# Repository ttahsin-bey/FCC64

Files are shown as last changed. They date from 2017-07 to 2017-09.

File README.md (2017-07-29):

# FCC64
Final Chess Card - Forum64 Edition

Current Design:

Rendering

Recent Prototype:

Prototype

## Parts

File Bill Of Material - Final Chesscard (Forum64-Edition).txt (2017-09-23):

Ref	Product		Package	Value			Distri	Order-Code

R1	Resistor	0603	100k, 1%		Mouser	603-RC0603FR-07100KL
R2	Resistor	0603	100k, 1%		Mouser	603-RC0603FR-07100KL
R3	Resistor	0603	100k, 1%		Mouser	603-RC0603FR-07100KL
R4	Resistor	0603	100k, 1%		Mouser	603-RC0603FR-07100KL
R5	Resistor	0603	33R, 1%			Mouser	603-RC0603FR-0733RL
R6	Resistor	0603	3k4, 1%			Mouser	603-RC0603FR-073K4L
R7	Resistor	0603	1k15, 1%		Mouser	603-RC0603FR-071K15L
R8	Resistor	0603	2k2, 1%			Mouser	603-RC0603FR-072K2L
R9	Resistor	0603	2k2, 1%			Mouser	603-RC0603FR-072K2L
R10	Resistor	0603	2k2, 1%			Mouser	603-RC0603FR-072K2L
R11	Resistor	0603	2k2, 1%			Mouser	603-RC0603FR-072K2L
R12	Resistor	0603	2k2, 1%			Mouser	603-RC0603FR-072K2L

C1	Capacitor	1206	10µF/25V, X7R, MLCC	Mouser	603-CC126KKX7R8BB106
C2	Capacitor	1206	10µF/25V, X7R, MLCC	Mouser	603-CC126KKX7R8BB106
C3	Capacitor	0603	100nF/50V, X7R, MLCC	Mouser	603-CC603KRX7R9BB104
C4	Capacitor	0603	100nF/50V, X7R, MLCC	Mouser	603-CC603KRX7R9BB104
C5	Capacitor	0603	100nF/50V, X7R, MLCC	Mouser	603-CC603KRX7R9BB104
C6	Capacitor	0603	100nF/50V, X7R, MLCC	Mouser	603-CC603KRX7R9BB104
C7	Capacitor	0603	100nF/50V, X7R, MLCC	Mouser	603-CC603KRX7R9BB104
C8	Capacitor	0603	100nF/50V, X7R, MLCC	Mouser	603-CC603KRX7R9BB104
C9	Capacitor	0603	100nF/50V, X7R, MLCC	Mouser	603-CC603KRX7R9BB104
C10	Capacitor	0603	100nF/50V, X7R, MLCC	Mouser	603-CC603KRX7R9BB104
C11	Capacitor	0603	100nF/50V, X7R, MLCC	Mouser	603-CC603KRX7R9BB104
C12	Capacitor	0603	100nF/50V, X7R, MLCC	Mouser	603-CC603KRX7R9BB104
C13	Capacitor	0603	100nF/50V, X7R, MLCC	Mouser	603-CC603KRX7R9BB104
C14	Capacitor	0603	18pF/25V, NPO, MLCC	Mouser	603-CC603JRNPO8BN180
C15	Capacitor	0603	18pF/25V, NPO, MLCC	Mouser	603-CC603JRNPO8BN180
C16	Capacitor	0603	10nF/25V, X7R, MLCC	Mouser	603-CC603KRX7R9BB103
C17	Capacitor	0603	100nF/50V, X7R, MLCC	Mouser	603-CC603KRX7R9BB104
C18	Capacitor	0603	100nF/50V, X7R, MLCC	Mouser	603-CC603KRX7R9BB104
C19	Capacitor	0603	10nF/25V, X7R, MLCC	Mouser	603-CC603KRX7R9BB103
C20	Capacitor	0603	100nF/50V, X7R, MLCC	Mouser	603-CC603KRX7R9BB104
C21	Capacitor	0603	100nF/50V, X7R, MLCC	Mouser	603-CC603KRX7R9BB104
C22	Capacitor	0603	100nF/50V, X7R, MLCC	Mouser	603-CC603KRX7R9BB104
C23	Capacitor	0603	100nF/50V, X7R, MLCC	Mouser	603-CC603KRX7R9BB104

D1	Diode		0603	1N4148			Reichlt	TS 4148-0603
D2	Diode		0603	1N4148			Reichlt	TS 4148-0603

U1	IC (EPROM)	PDIP	AT27C256R-70PU		Mouser	556-AT27C256R70PU
U1'	IC-Socket	DIL28	-			Reichlt	GS 28P
U2	IC (CPLD)	TQFP100	ATF1504AS-10AU100	Mouser	556-AF1504AS10AU100
U3	IC (CPU)	QFP44	W65C02S6TQG-14		Mouser	955-W65C02S6TQG-14
U4	IC (CLOCK)	SSOP28	ICS525-01RLF		Mouser	972-525-01RLF
U5	IC (EPROM)	PDIP	AT27C256R-70PU		Mouser	556-AT27C256R70PU
U5'	IC-Socket	DIL28	-			Reichlt	GS 28P
U6	IC (RAM)	TSOP28	CY62256NLL-55ZXI	Mouser	727-CY62256NLL55ZXIT
U7	IC (Supervisor)	MSOP10	TPS3613-01		Mouser	595-TPS3613-01DGS

X1	Crystal		7A	12MHz, 18pF		Mouser	717-7A-12.000MAAJ-T

P1	JTAG-Connector	n.a.	2*5 Pinheader 2mm	Reichlt	MPE 150-3-010

S1	DIP-Switch	DIP-6	NT03			Reichlt NT 03
SW1	Pushbutton	n.a.	JTP1236B		Reichlt	TASTER 3305B

Bat1	CR2032		n.a.	Varta CR 2032		Reichlt	CR 2032 VAR
Bat1'	"-"-Terminal	n.a.	Keystone 2990		Mouser	534-2990
Bat1'	"+"-Terminal	n.a.	Keystone 3003		Mouser	534-3003

PCB	2 Layer, 1.6mm

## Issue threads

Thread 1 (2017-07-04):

Platine klemmt leicht im icomp-Gehäuse

ttahsin-bey, 2017-07-04:
Die Platine ist an den Stellen, wo die Haltenasen aus dem icomp-Gehäuse rausragen, zu breit. Die Breite der Platine sollte um 0,1mm bis 0,2mm an jeder Haltenase verringert werden...

ttahsin-bey, 2017-07-10:
PCB is now recessed by 0,2mm at each clamp.

PCB should now fit smoothly.

Closed 2017-07-10.

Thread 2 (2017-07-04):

Footprint für U3 (W65C02-CPU) zu klein

ttahsin-bey, 2017-07-04:
Der Footprint für U3 muss überarbeitet werden...

ttahsin-bey, 2017-07-10:
Footprint corrected.

Thanks to WDC for providing the package outline drawing.

Closed 2017-07-10.

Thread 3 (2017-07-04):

RAM geht bei Batterieversorgung nicht in Standby

ttahsin-bey, 2017-07-04:
Das /CS-Signal geht bei Batteriebetrieb auf Low und selektiert damit das RAM. Dadurch wird ein erhöhter Stromverbrauch erzeugt. Das /CS-Signal muss bei Batteriebetrieb ebenfalls auf High (Pegel der Batterie, Pegel von Vcc) gelegt werden...

ttahsin-bey, 2017-07-10:
New battery supervisor IC used to resolve issue.

IC used is TPS3613-01.

Closed 2017-07-10.

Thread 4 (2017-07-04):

D7 lässt sich nicht auf die Konfig-Flipflops legen

ttahsin-bey, 2017-07-04:
Die Belegung des CPLD lässt es nicht zu, D7 vom C64 auf ein Konfig-Flipflop zu legen, um bei Bedarf den Zugriff auf die Konfig-Register zu unterbinden.

Lösungsmöglichkeit: In einer späteren Revision der Platine D5 mit D7 am CPLD tauschen, dann klappt das Übersetzen der Logikgleichungen wieder...

ttahsin-bey, 2017-07-10:
Current revision has D5 and D7 from the C64-EPROM to the CPLD swapped so that the CPLD-Sources are compiling fine now.

Closed 2017-07-10.

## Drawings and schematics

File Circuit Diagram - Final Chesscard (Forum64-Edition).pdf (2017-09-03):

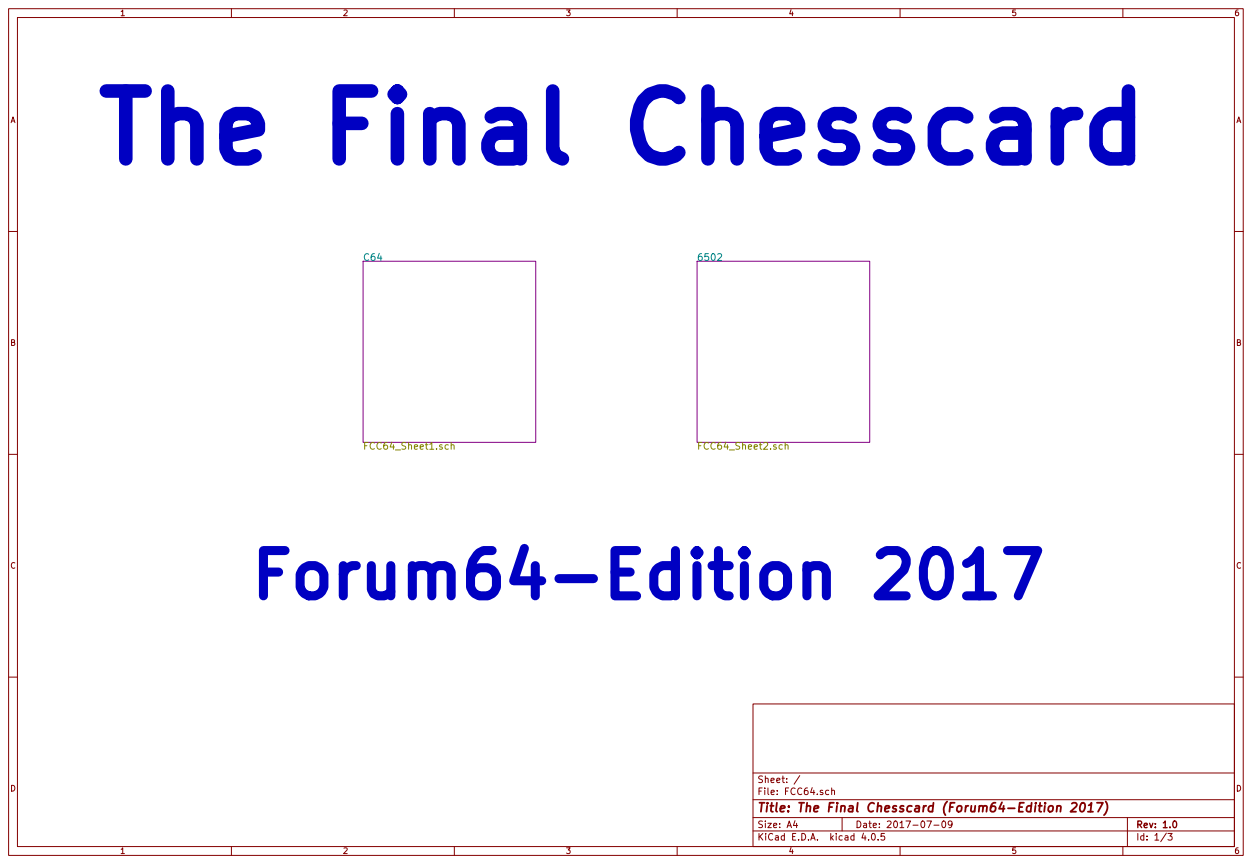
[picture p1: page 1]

Id: 1/3 Title: The Final Chesscard (Forum64-Edition 2017) File: FCC64.sch Sheet: /

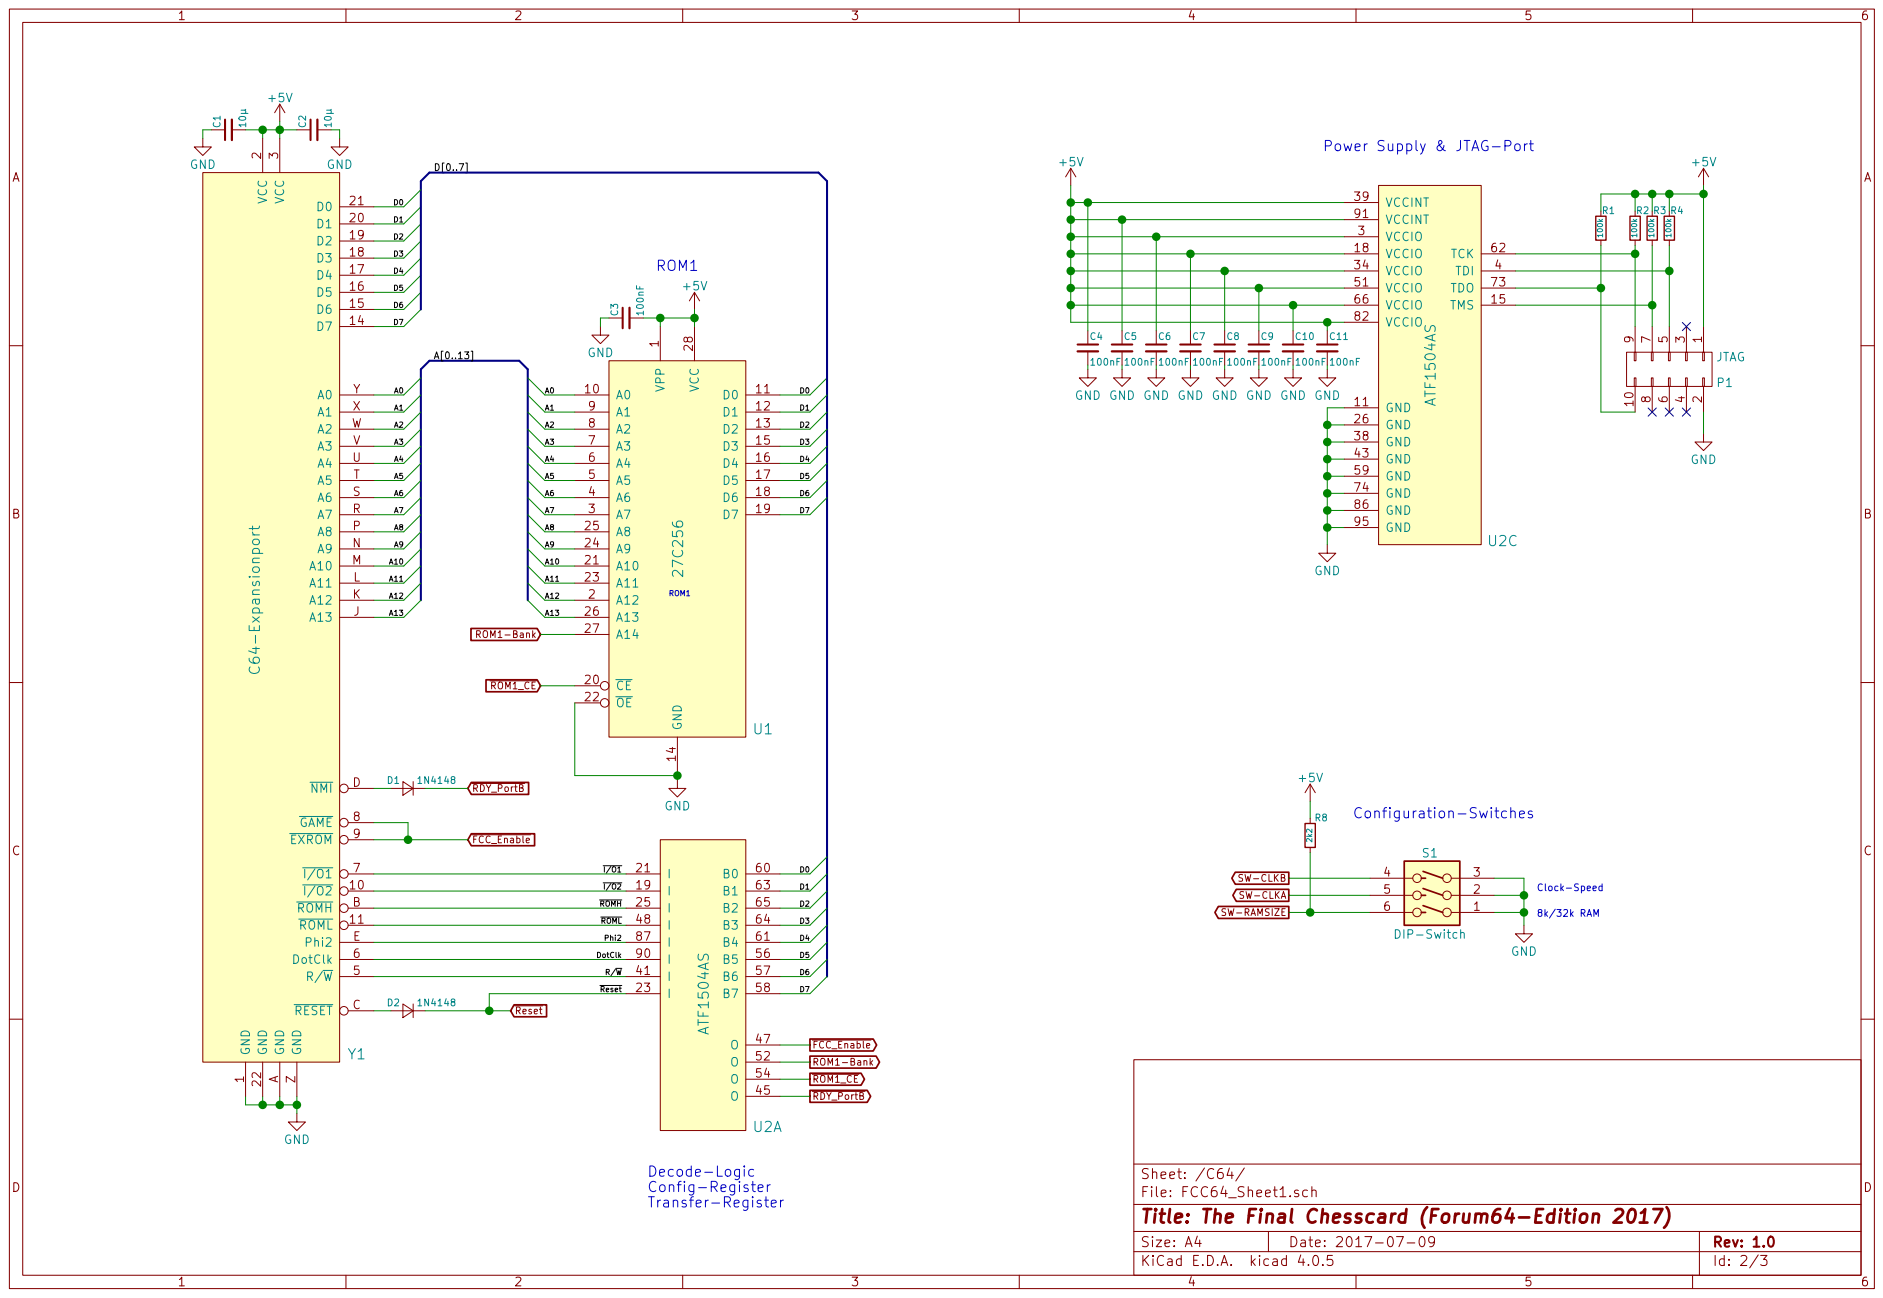
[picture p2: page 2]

Power Supply & JTAG-Port

Id: 2/3 Title: The Final Chesscard (Forum64-Edition 2017)

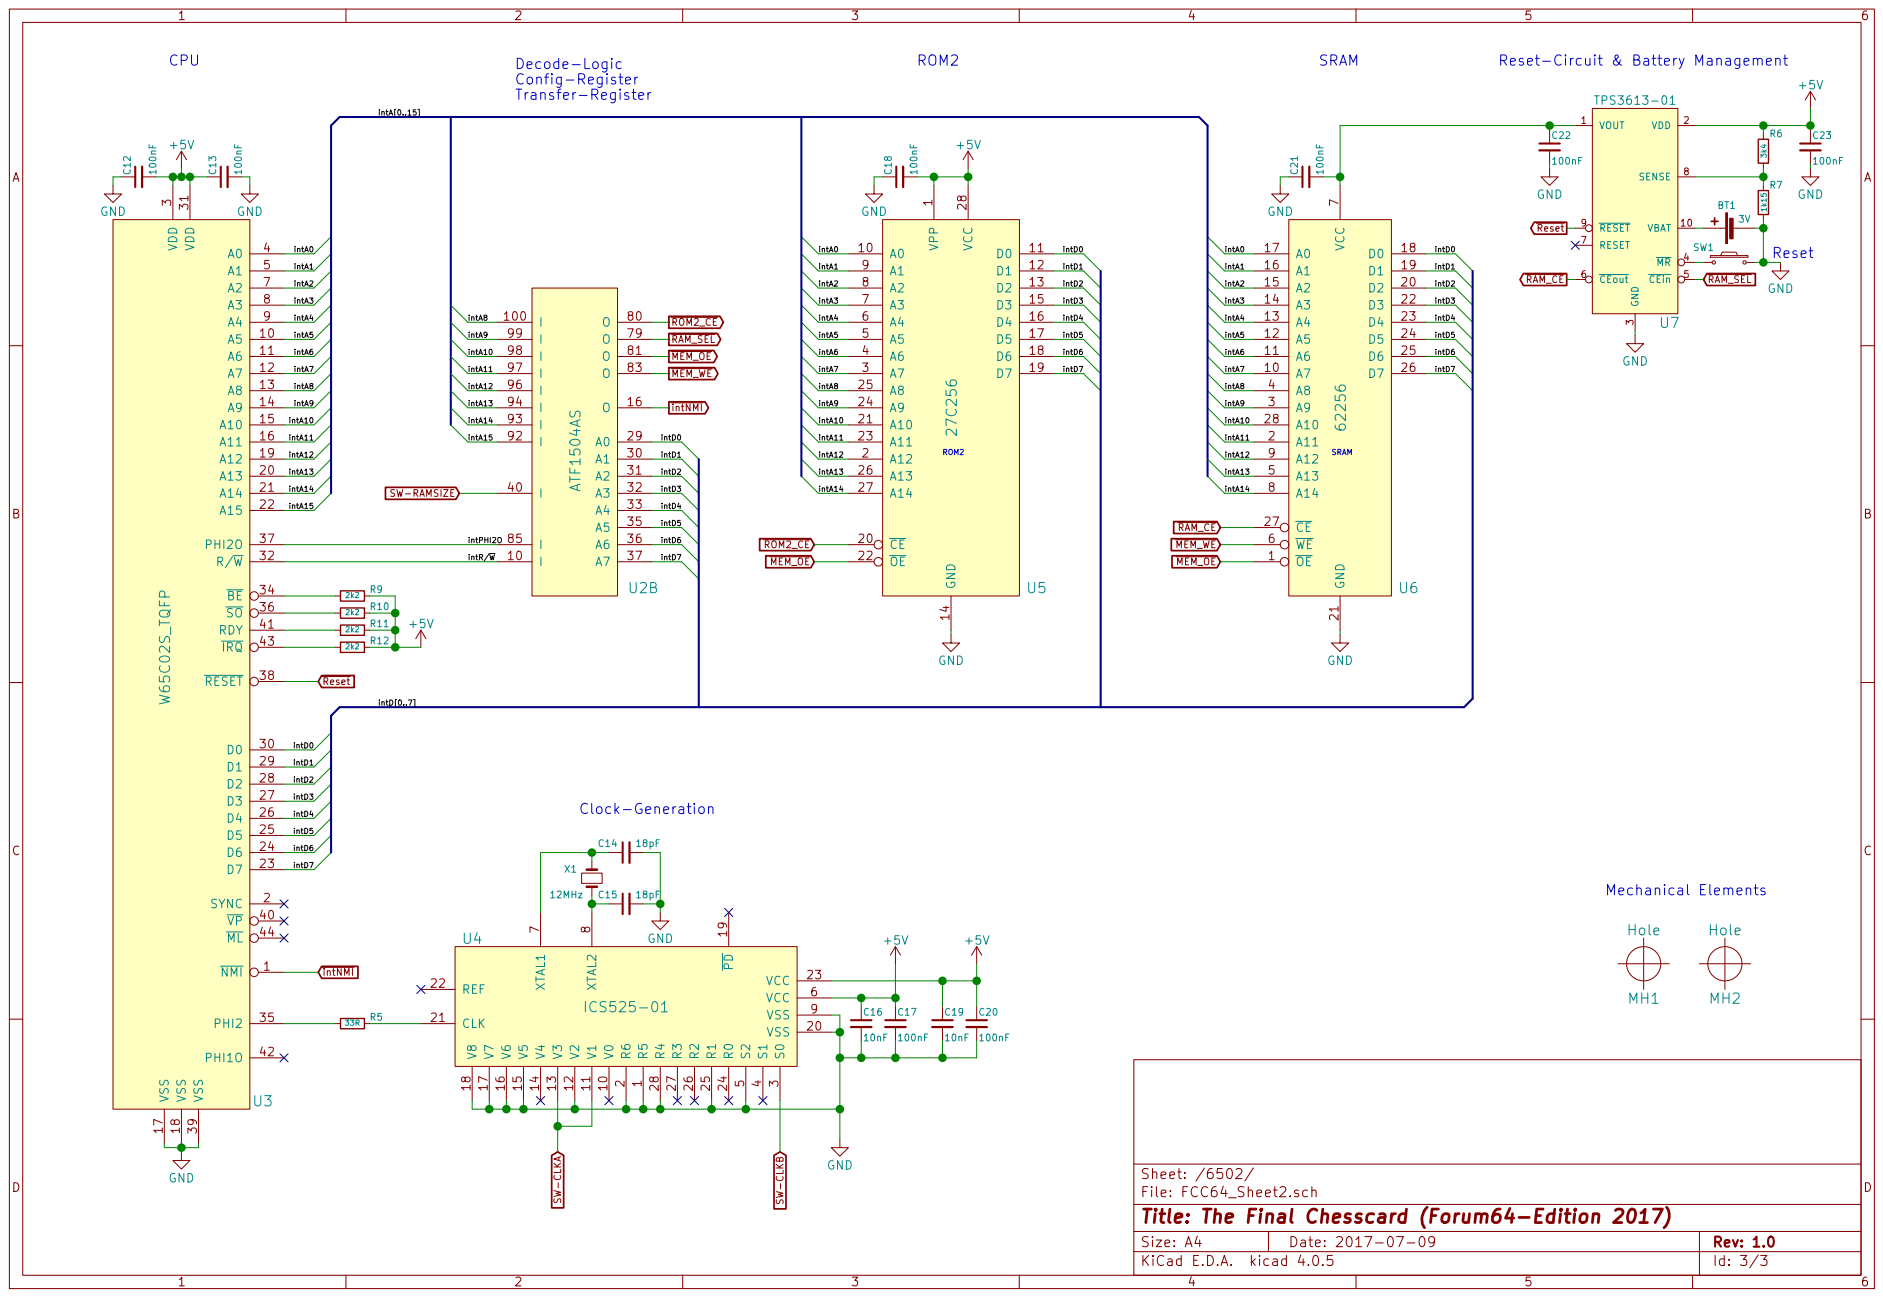
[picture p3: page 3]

intA15 +5V
File: FCC64_Sheet2.sch Sheet: /6502/ VPP

Reset-Circuit & Battery Management R5

Reset MH1 Hole Mechanical Elements MH2 Hole

3 MR 4 CEin 5 CEout 6 RESET 7 SENSE 8 RESET 9 VBAT 10 U7

1 A12 2 A7 3 A6 4 A5 5 A4 6 A3 7 A2 8 A1 9 A0 10 CE 20 D0 11 A10 21 D1 12 OE 22 D2 13 A11 23 GND 14 A9 24 D3 15 A8 25 D4 16 A13 26 D5 17 A14 27 D6 18 VCC 28 D7 19 U5 27C256

8 VSS 9 V0 10 VSS 20 V1 11 CLK 21 V2 12 REF 22 V3 13 VCC 23 V4 14 R0 24 V5 15 R1 25 V6 16 R2 26 V7 17 R3 27 V8 18 R4 28 PD 19 U4

Id: 3/3 Title: The Final Chesscard (Forum64-Edition 2017)

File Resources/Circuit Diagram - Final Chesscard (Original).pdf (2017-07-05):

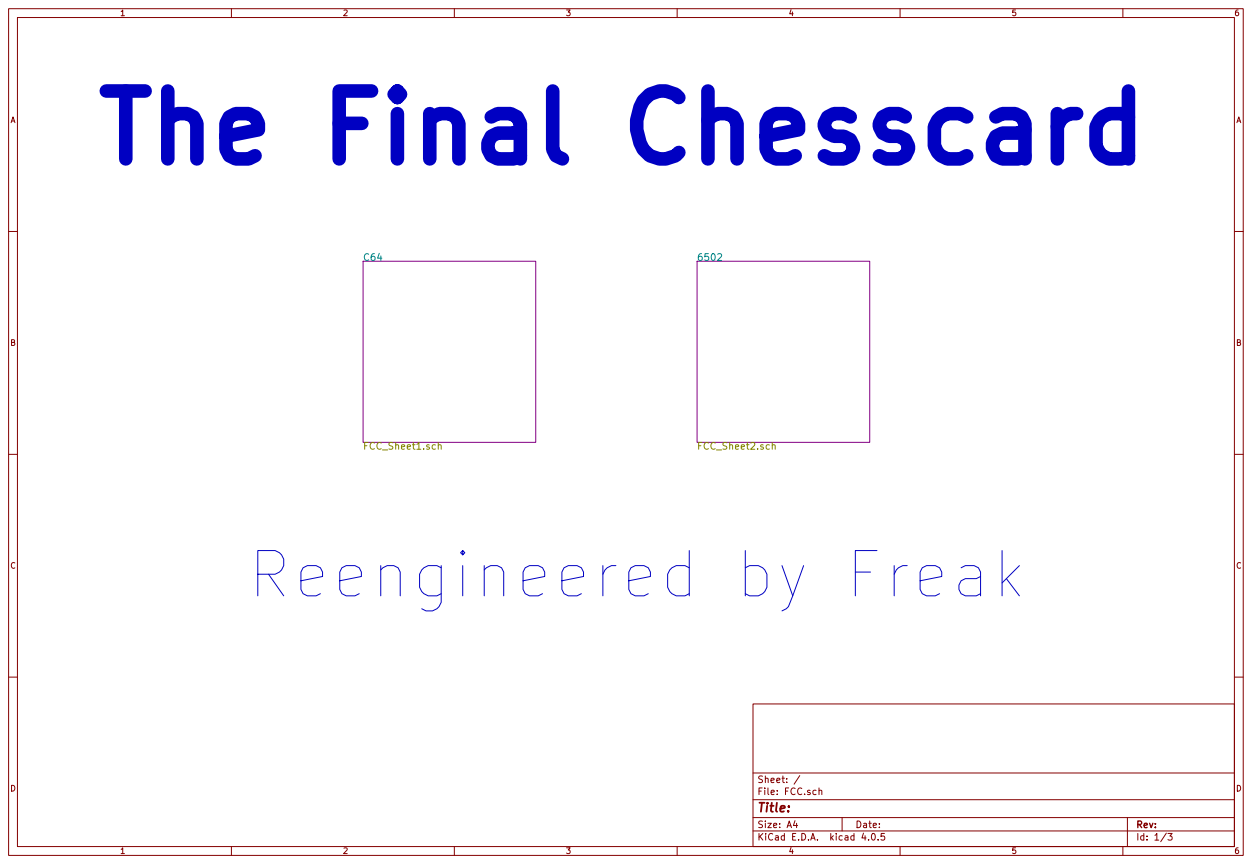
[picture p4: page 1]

Id: 1/3 Title: File: FCC.sch Sheet: /

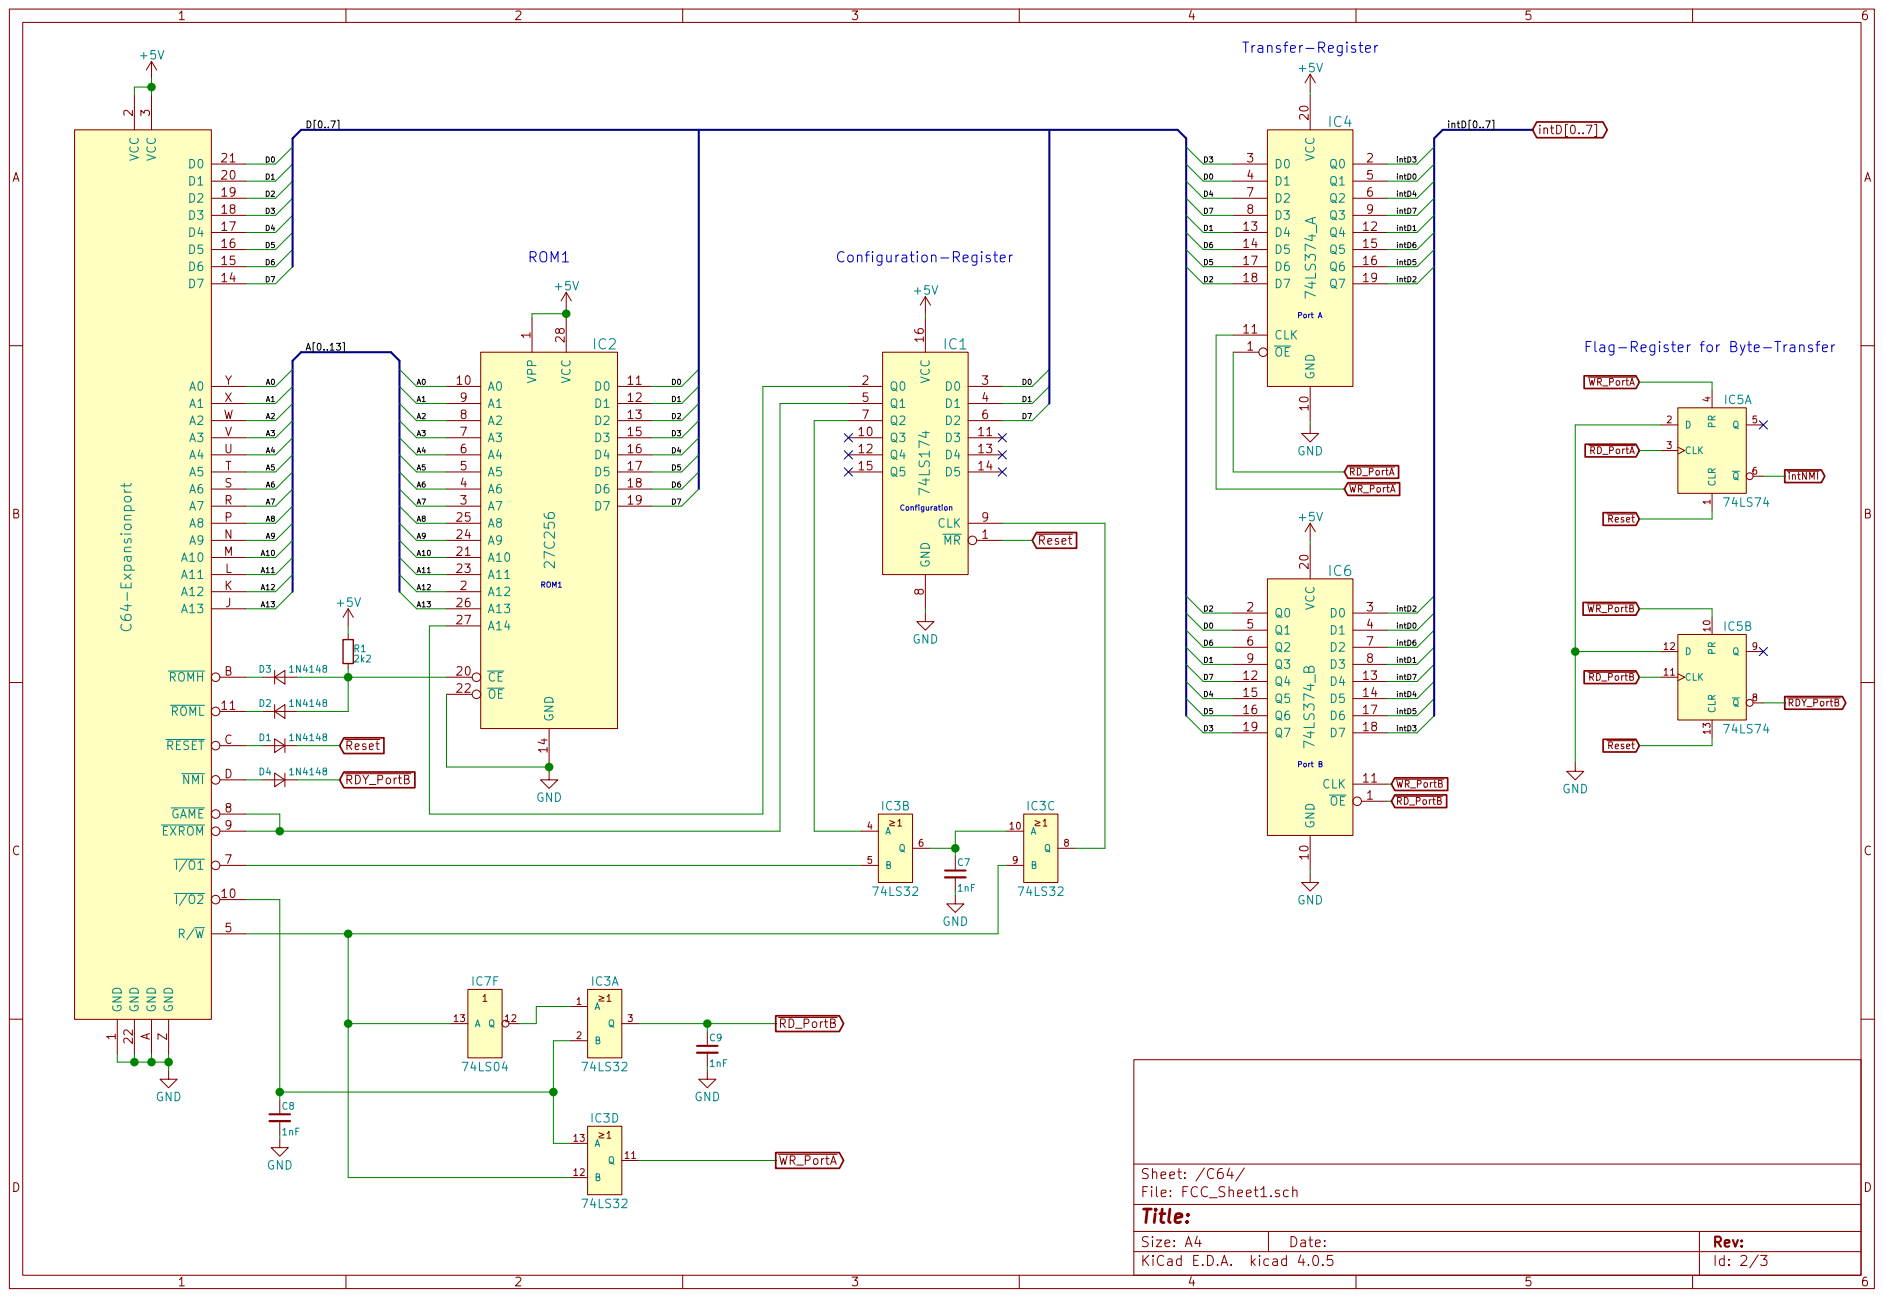
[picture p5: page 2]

intNMI Flag-Register for Byte-Transfer
RD_PortA WR_PortA WR_PortB RD_PortB Reset Reset

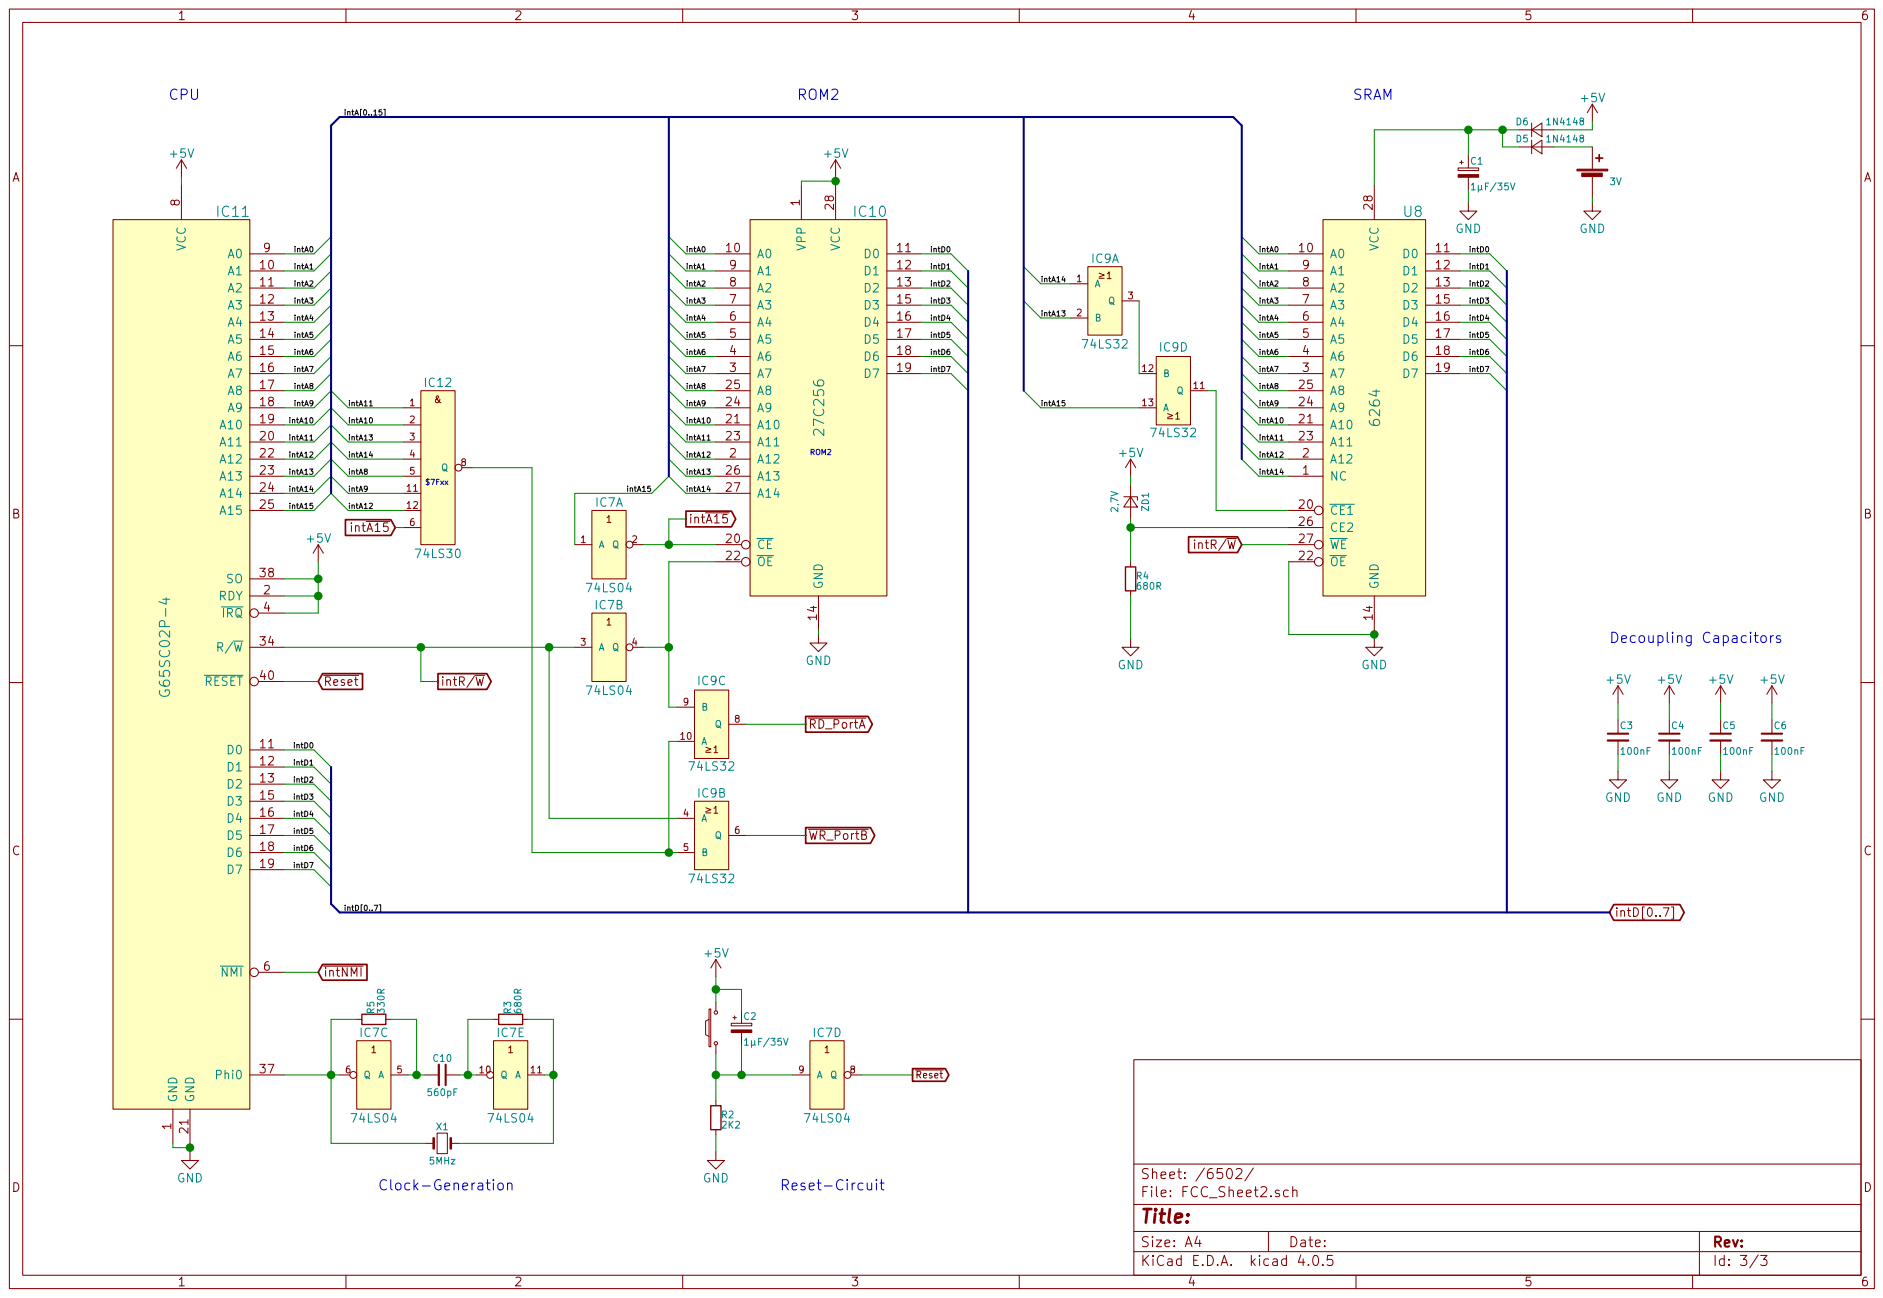
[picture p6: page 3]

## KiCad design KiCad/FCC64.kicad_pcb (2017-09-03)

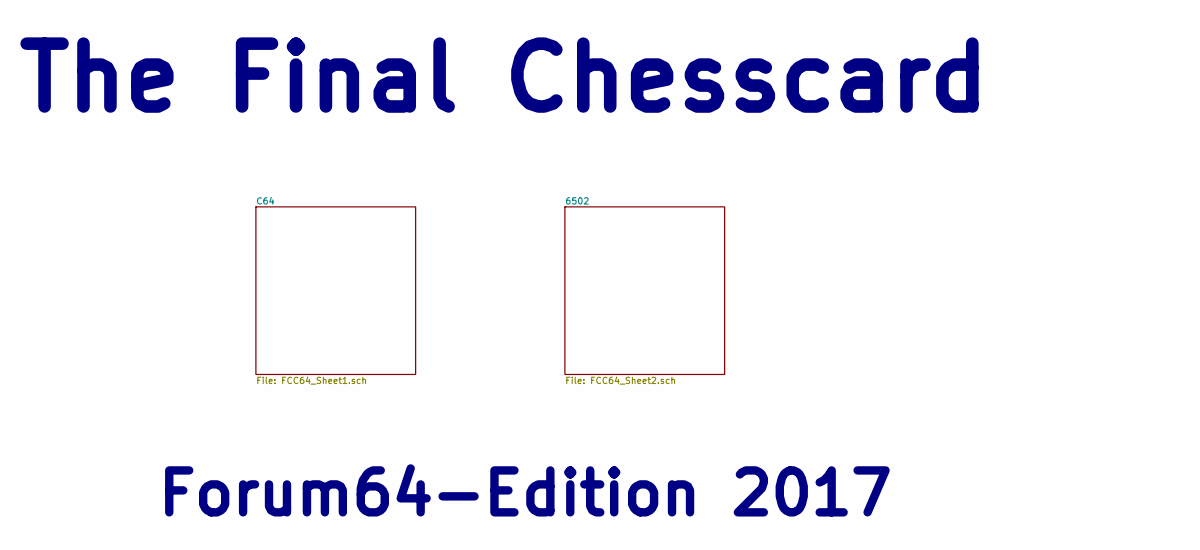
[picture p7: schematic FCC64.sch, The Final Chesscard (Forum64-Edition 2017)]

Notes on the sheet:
The Final Chesscard
Forum64-Edition 2017

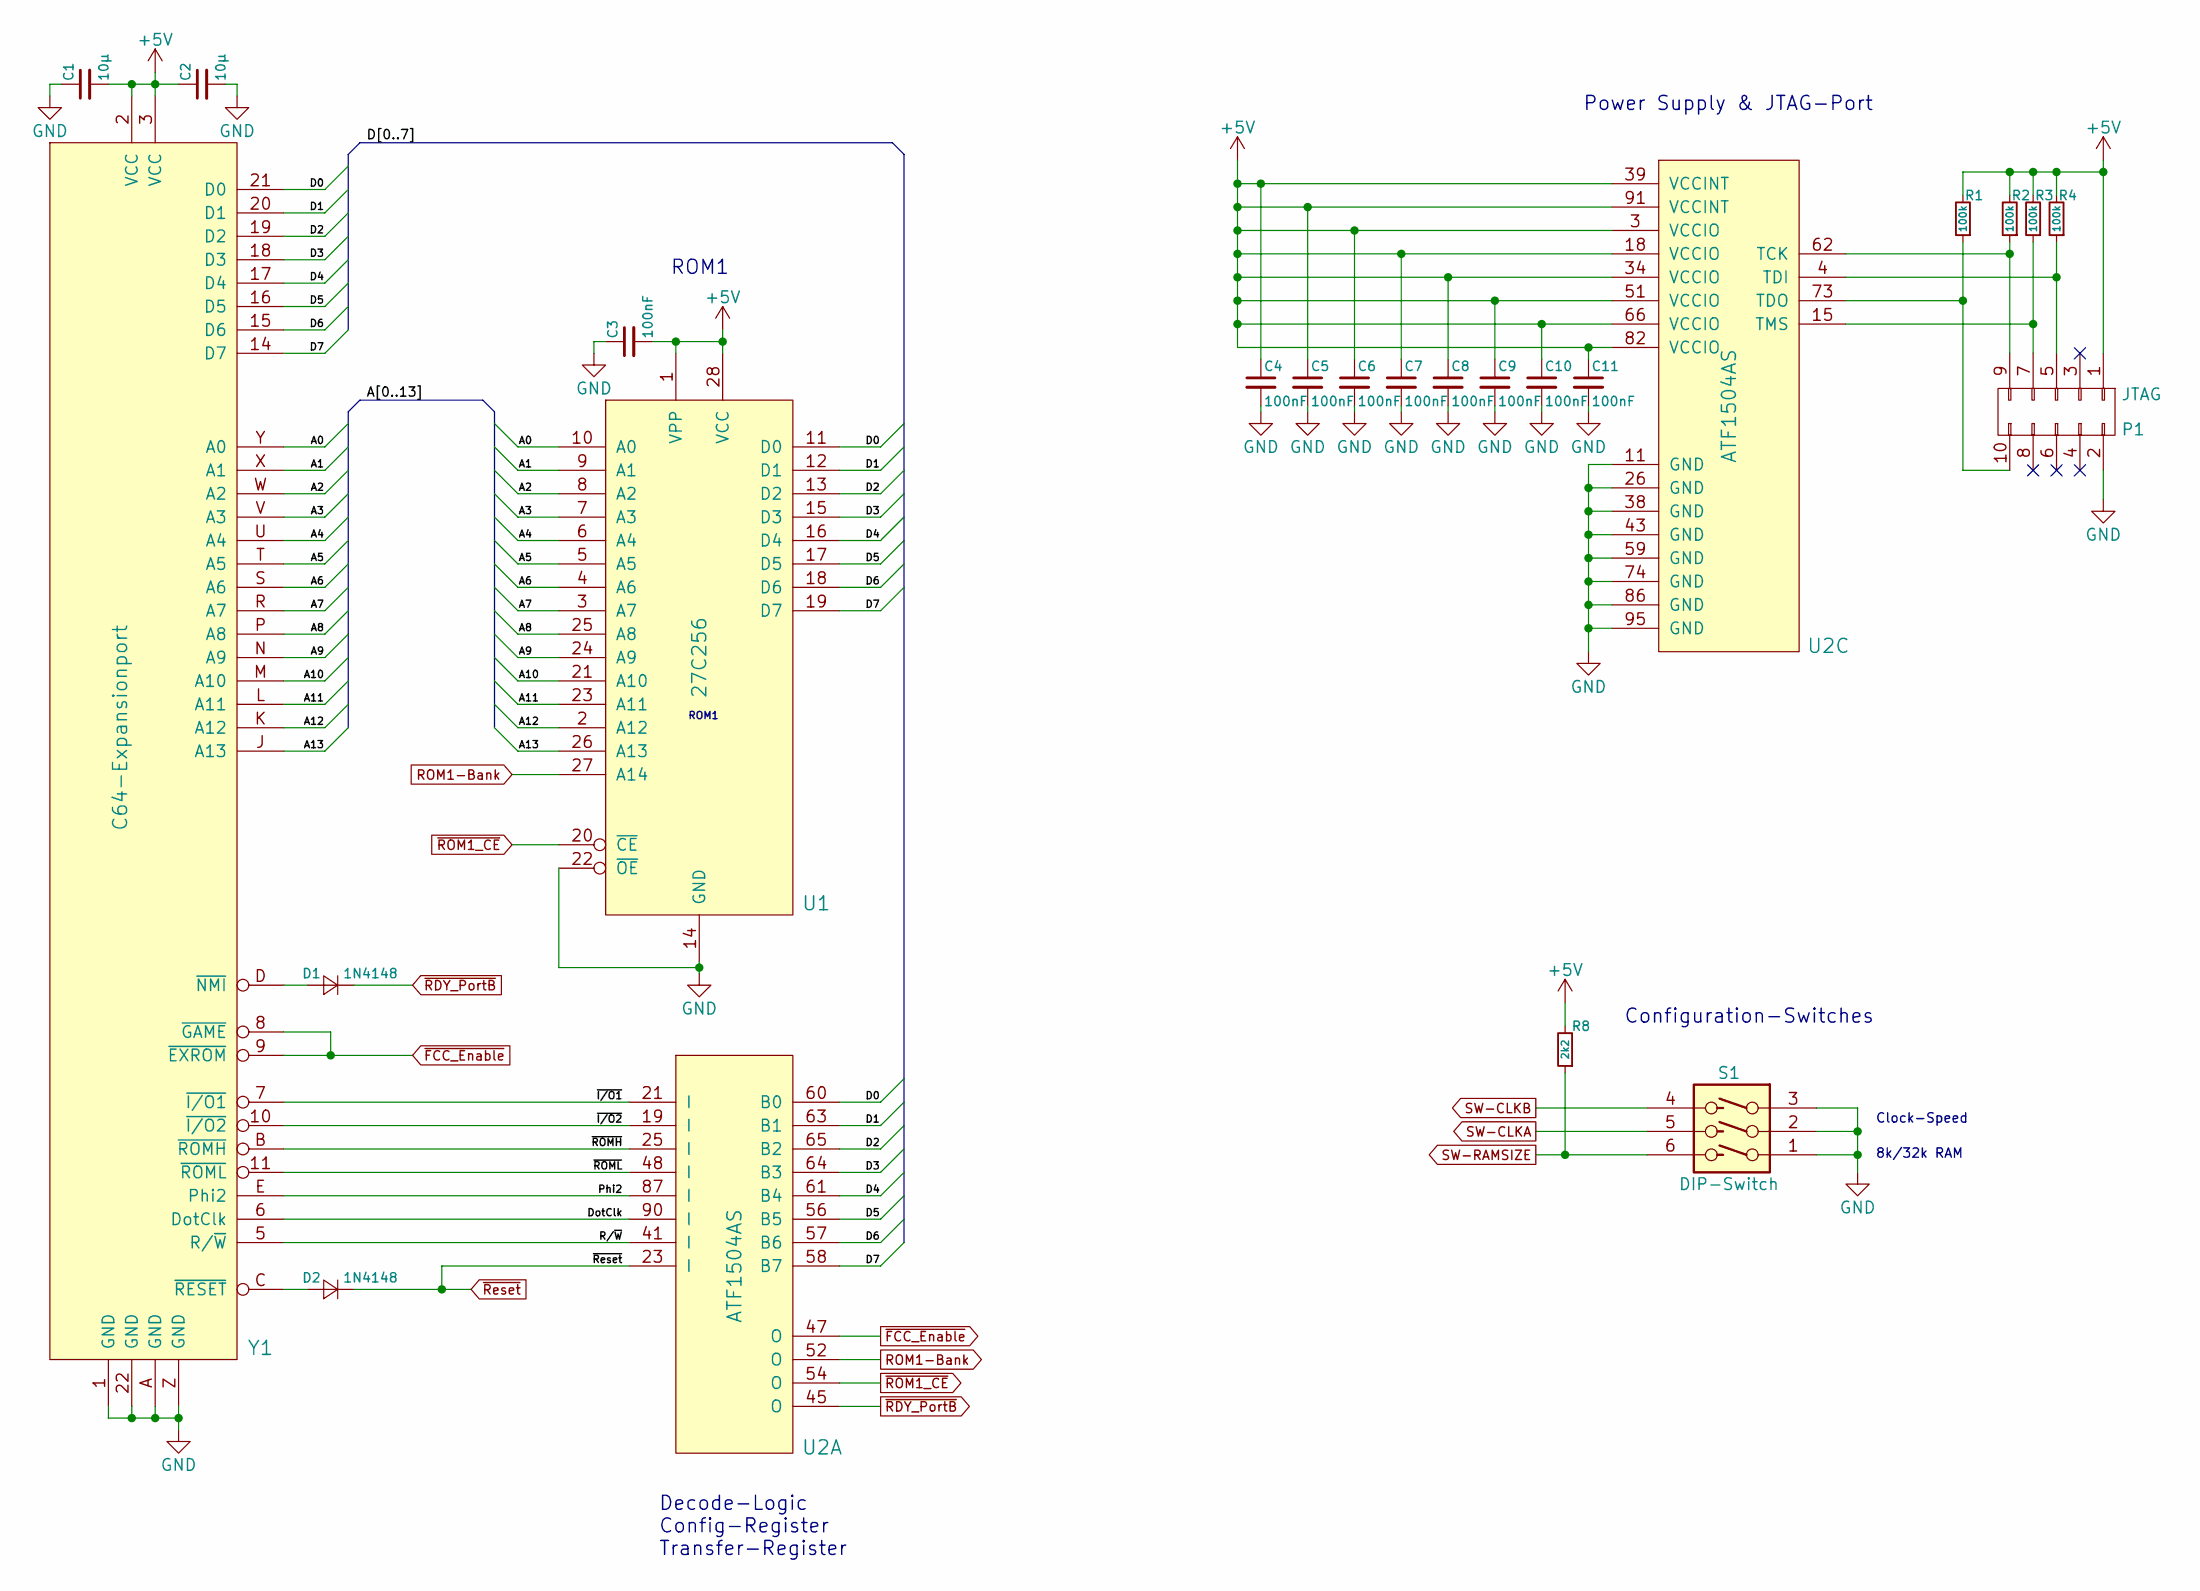
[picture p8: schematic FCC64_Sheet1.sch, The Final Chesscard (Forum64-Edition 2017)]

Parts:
C1, C2: 10µ; TTB_C1206
C3, C4, C5, C6, C7, C8, C9, C10, C11: 100nF; TTB_C0603
D1, D2: 1N4148; TTB_D0603
P1: JTAG; Pin_Header_Straight_2x05_Pitch2.00mm
R1, R2, R3, R4: 100k; TTB_R0603
R8: 2k2; TTB_R0603
S1: DIP-Switch; TTB_DIPSwitch3
U1: 27C256; TTB_DIL28
U2: ATF1504AS; TTB_TQFP100
Y1: C64-Expansionport; TTB_C64_Expansionport

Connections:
+5V: C1.2, C2.1, C3.2, C4.1, C5.1, C6.1, C7.1, C8.1, C9.1, C10.1, C11.1, P1.1, R1.2, R2.2, R3.2, R4.2, R8.2, U1.1 (VPP), U1.28 (VCC), U2.3 (VCCIO), U2.18 (VCCIO), U2.34 (VCCIO), U2.39 (VCCINT), U2.51 (VCCIO), U2.66 (VCCIO), U2.82 (VCCIO), U2.91 (VCCINT), Y1.2 (VCC), Y1.3 (VCC); also elsewhere on the board
/C64/A0: U1.10 (A0), Y1.Y (A0)
/C64/A1: U1.9 (A1), Y1.X (A1)
/C64/A2: U1.8 (A2), Y1.W (A2)
/C64/A3: U1.7 (A3), Y1.V (A3)
/C64/A4: U1.6 (A4), Y1.U (A4)
/C64/A5: U1.5 (A5), Y1.T (A5)
/C64/A6: U1.4 (A6), Y1.S (A6)
/C64/A7: U1.3 (A7), Y1.R (A7)
/C64/A8: U1.25 (A8), Y1.P (A8)
/C64/A9: U1.24 (A9), Y1.N (A9)
/C64/A10: U1.21 (A10), Y1.M (A10)
/C64/A11: U1.23 (A11), Y1.L (A11)
/C64/A12: U1.2 (A12), Y1.K (A12)
/C64/A13: U1.26 (A13), Y1.J (A13)
/C64/D0: U1.11 (D0), U2.60 (B0), Y1.21 (D0)
/C64/D1: U1.12 (D1), U2.63 (B1), Y1.20 (D1)
/C64/D2: U1.13 (D2), U2.65 (B2), Y1.19 (D2)
/C64/D3: U1.15 (D3), U2.64 (B3), Y1.18 (D3)
/C64/D4: U1.16 (D4), U2.61 (B4), Y1.17 (D4)
/C64/D5: U1.17 (D5), U2.56 (B7), Y1.16 (D5)
/C64/D6: U1.18 (D6), U2.57 (B6), Y1.15 (D6)
/C64/D7: U1.19 (D7), U2.58 (B5), Y1.14 (D7)
/C64/DotClk: U2.90 (I), Y1.6 (DotClk)
/C64/Phi2: U2.87 (I), Y1.E (Phi2)
/C64/R/~W: U2.41 (I), Y1.5 (R/~W)
/C64/~I/O1: U2.21 (I), Y1.7 (~I/O1)
/C64/~I/O2: U2.19 (I), Y1.10 (~I/O2)
/C64/~ROMH: U2.25 (I), Y1.B (~ROMH)
/C64/~ROML: U2.48 (I), Y1.11 (~ROML)
GND: C1.1, C2.2, C3.1, C4.2, C5.2, C6.2, C7.2, C8.2, C9.2, C10.2, C11.2, P1.2, S1.1, S1.2, S1.3, U1.14 (GND), U1.22 (~OE), U2.11 (GND), U2.26 (GND), U2.38 (GND), U2.43 (GND), U2.59 (GND), U2.74 (GND), U2.86 (GND), U2.95 (GND), Y1.1 (GND), Y1.22 (GND), Y1.A (GND), Y1.Z (GND); also elsewhere on the board
unnamed: D1.2 (A), Y1.D (~NMI)
unnamed: D2.2 (A), Y1.C (~RESET)
unnamed: P1.5, R4.1, U2.4 (TDI)
unnamed: P1.7, R3.1, U2.15 (TMS)
unnamed: P1.9, R2.1, U2.62 (TCK)
unnamed: P1.10, R1.1, U2.73 (TDO)
ROM1-Bank: U1.27 (A14), U2.52 (O)
SW-CLKA: S1.5; also elsewhere on the board
SW-CLKB: S1.4; also elsewhere on the board
SW-RAMSIZE: R8.1, S1.6; also elsewhere on the board
~FCC_Enable: U2.47 (O), Y1.8 (~GAME), Y1.9 (~EXROM)
~RDY_PortB: D1.1 (K), U2.45 (O)
~ROM1_CE: U1.20 (~CE), U2.54 (O)
~Reset: D2.1 (K), U2.23 (I); also elsewhere on the board

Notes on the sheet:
ROM1
Decode-Logic Config-Register Transfer-Register
Power Supply & JTAG-Port
Configuration-Switches
8k/32k RAM
Clock-Speed

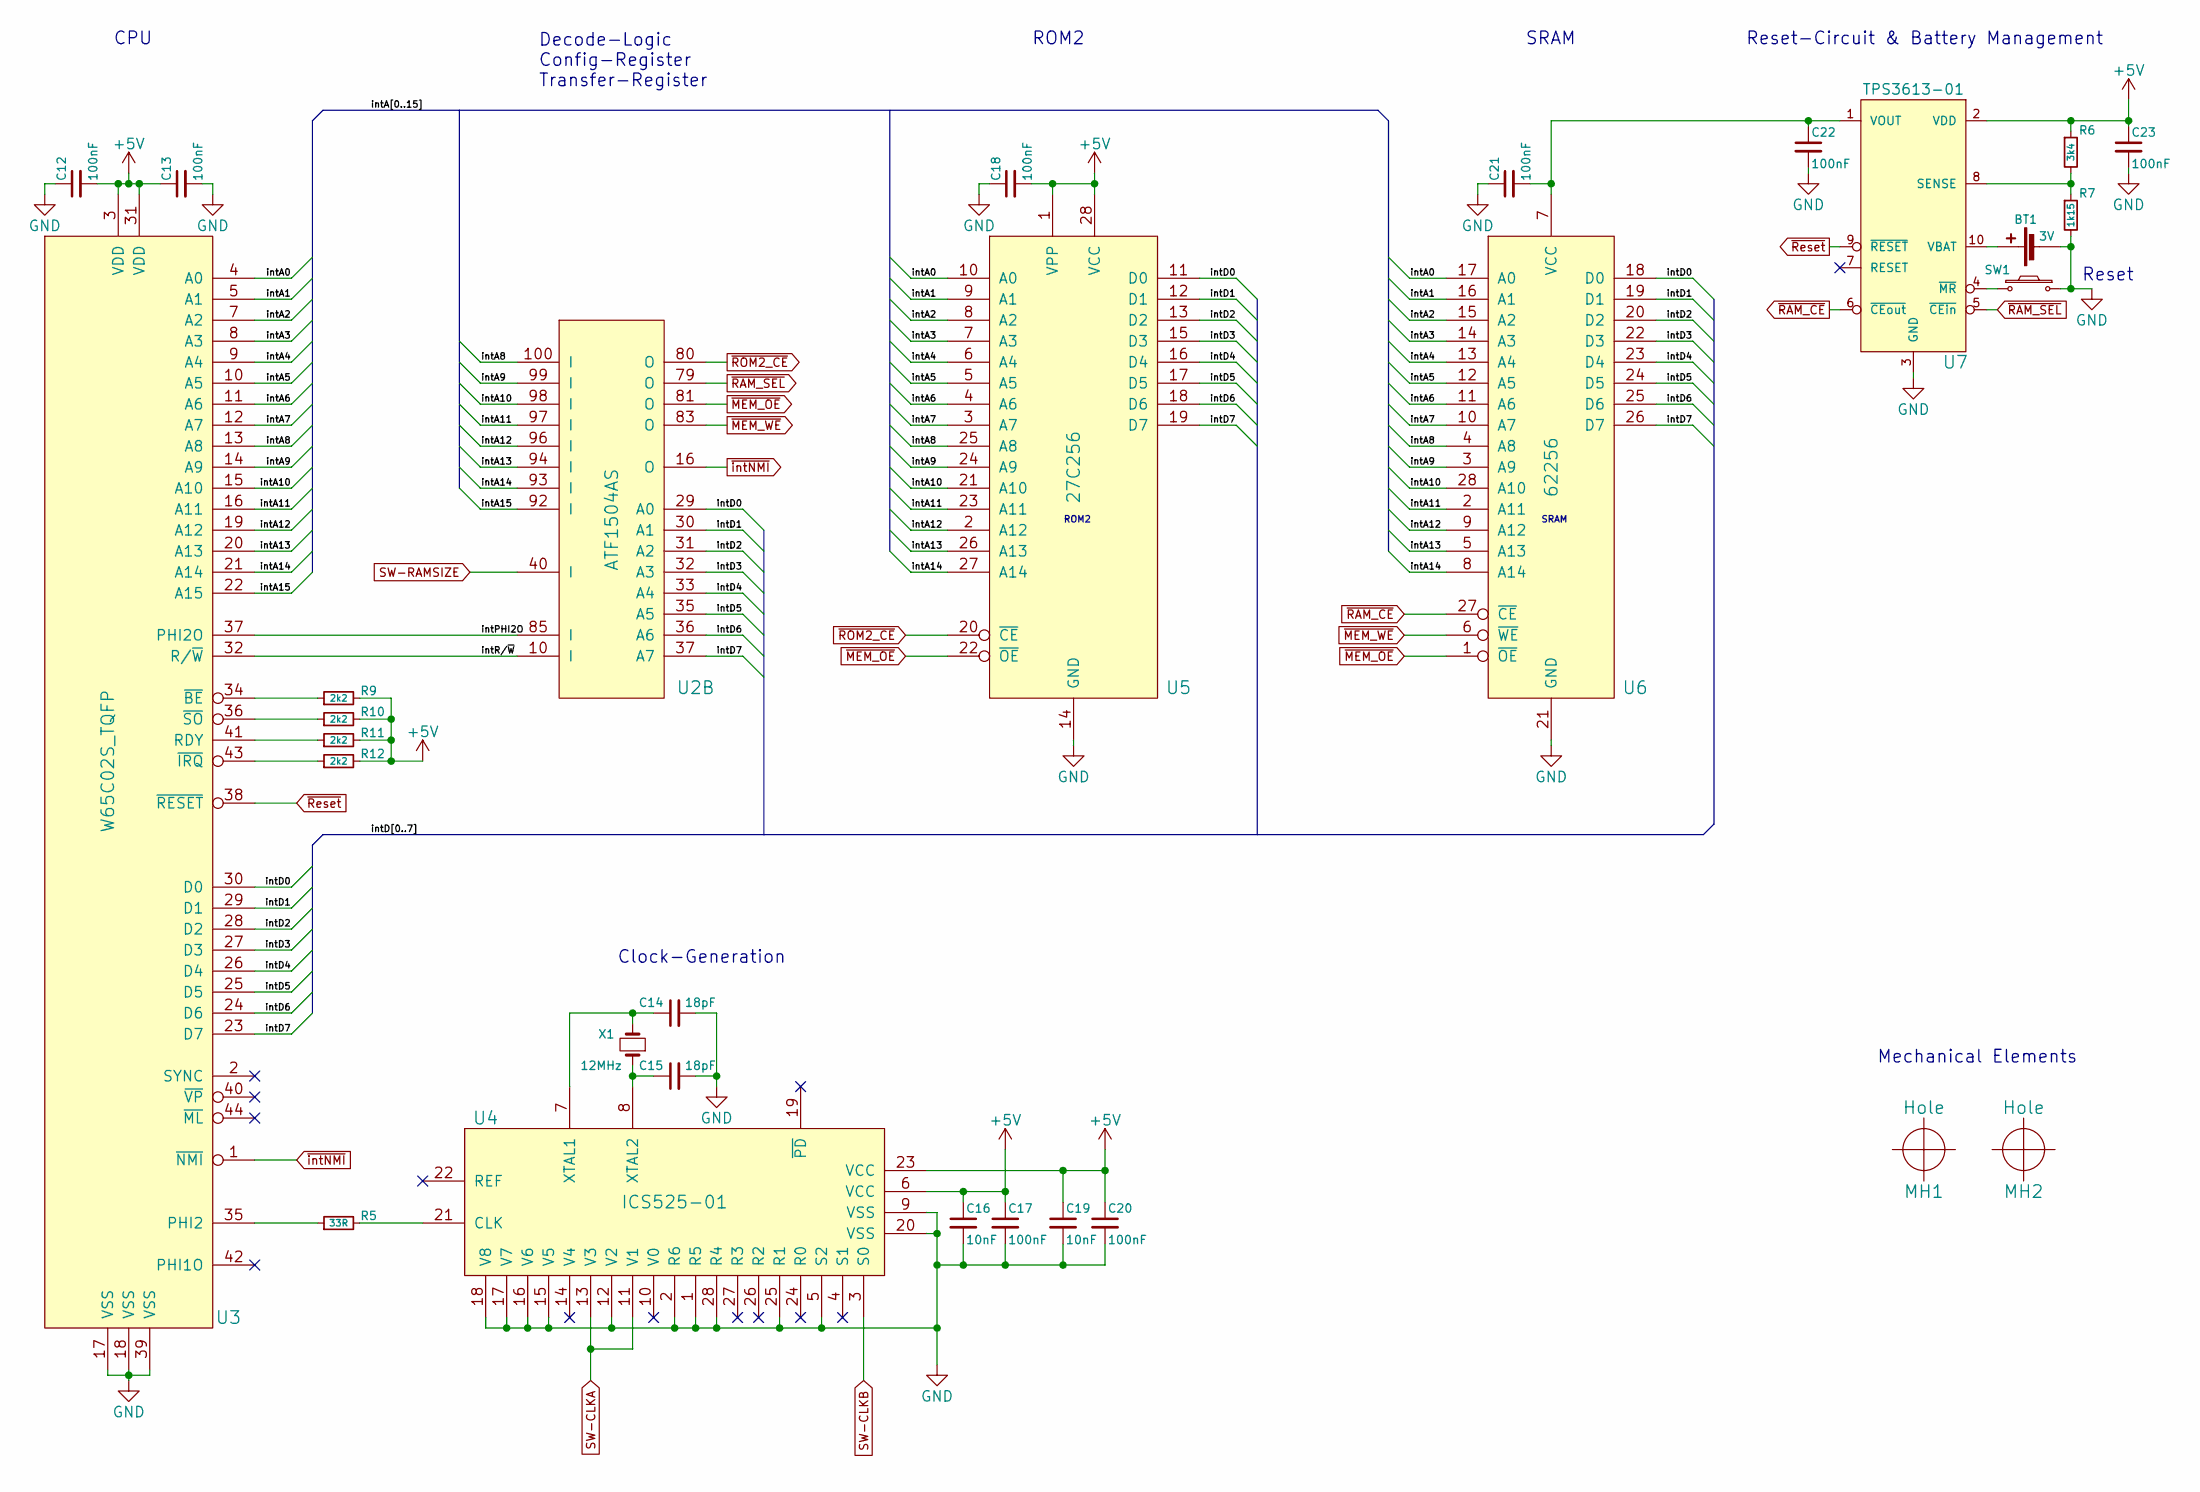
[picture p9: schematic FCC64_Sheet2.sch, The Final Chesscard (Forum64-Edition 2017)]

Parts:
BT1: 3V; TTB_Batteriehalter
C12, C13, C17, C18, C20, C21, C22, C23: 100nF; TTB_C0603
C14, C15: 18pF; TTB_C0603wide
C16, C19: 10nF; TTB_C0603
MH1: Hole; TTB_Hole4,8mm
MH2: Hole; TTB_Hole3,1mm
R5: 33R; TTB_R0603
R6: 3k4; TTB_R0603
R7: 1k15; TTB_R0603
R9, R10, R11, R12: 2k2; TTB_R0603
SW1: Reset; TTB_Pushbutton_3305
U2: ATF1504AS; TTB_TQFP100
U3: W65C02S_TQFP; TTB_W65C02
U4: ICS525-01; TTB_TSSOP28
U5: 27C256; TTB_DIL28
U6: 62256; TTB_TSOP1_28
U7: TPS3613-01; TTB_MSOP10
X1: 12MHz; TTB_7A

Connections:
+5V: C12.2, C13.1, C16.1, C17.1, C18.2, C19.1, C20.1, C23.1, R6.1, R9.2, R10.2, R11.2, R12.2, U3.3 (VDD), U3.31 (VDD), U4.6 (VCC), U4.23 (VCC), U5.1 (VPP), U5.28 (VCC), U7.2 (VDD); also elsewhere on the board
/6502/intA0: U3.4 (A0), U5.10 (A0), U6.17 (A0)
/6502/intA1: U3.5 (A1), U5.9 (A1), U6.16 (A1)
/6502/intA2: U3.7 (A2), U5.8 (A2), U6.15 (A2)
/6502/intA3: U3.8 (A3), U5.7 (A3), U6.14 (A3)
/6502/intA4: U3.9 (A4), U5.6 (A4), U6.13 (A4)
/6502/intA5: U3.10 (A5), U5.5 (A5), U6.12 (A5)
/6502/intA6: U3.11 (A6), U5.4 (A6), U6.11 (A6)
/6502/intA7: U3.12 (A7), U5.3 (A7), U6.10 (A7)
/6502/intA8: U2.100 (I), U3.13 (A8), U5.25 (A8), U6.4 (A8)
/6502/intA9: U2.99 (I), U3.14 (A9), U5.24 (A9), U6.3 (A9)
/6502/intA10: U2.98 (I), U3.15 (A10), U5.21 (A10), U6.28 (A10)
/6502/intA11: U2.97 (I), U3.16 (A11), U5.23 (A11), U6.2 (A11)
/6502/intA12: U2.96 (I), U3.19 (A12), U5.2 (A12), U6.9 (A12)
/6502/intA13: U2.94 (I), U3.20 (A13), U5.26 (A13), U6.5 (A13)
/6502/intA14: U2.93 (I), U3.21 (A14), U5.27 (A14), U6.8 (A14)
/6502/intA15: U2.92 (I), U3.22 (A15)
/6502/intD0: U2.29 (A0), U3.30 (D0), U5.11 (D0), U6.18 (D0)
/6502/intD1: U2.30 (A1), U3.29 (D1), U5.12 (D1), U6.19 (D1)
/6502/intD2: U2.31 (A2), U3.28 (D2), U5.13 (D2), U6.20 (D2)
/6502/intD3: U2.32 (A3), U3.27 (D3), U5.15 (D3), U6.22 (D3)
/6502/intD4: U2.33 (A4), U3.26 (D4), U5.16 (D4), U6.23 (D4)
/6502/intD5: U2.35 (A5), U3.25 (D5), U5.17 (D5), U6.24 (D5)
/6502/intD6: U2.36 (A6), U3.24 (D6), U5.18 (D6), U6.25 (D6)
/6502/intD7: U2.37 (A7), U3.23 (D7), U5.19 (D7), U6.26 (D7)
/6502/intPHI2O: U2.85 (I), U3.37 (PHI2O)
/6502/intR/~W: U2.10 (I), U3.32 (R/~W)
GND: BT1.2 (-), C12.1, C13.2, C14.2, C15.2, C16.2, C17.2, C18.1, C19.2, C20.2, C21.1, C22.2, C23.2, R7.2, SW1.1, U3.17 (VSS), U3.18 (VSS), U3.39 (VSS), U4.1 (R5), U4.2 (R6), U4.5 (S2), U4.9 (VSS), U4.12 (V2), U4.15 (V5), U4.16 (V6), U4.17 (V7), U4.18 (V8), U4.20 (VSS), U4.25 (R1), U4.28 (R4), U5.14 (GND), U6.21 (GND), U7.3 (GND); also elsewhere on the board
unnamed: BT1.1 (+), U7.10 (VBAT)
unnamed: C14.1, U4.7 (XTAL1), X1.2
unnamed: C15.1, U4.8 (XTAL2), X1.1
unnamed: C21.2, C22.1, U6.7 (VCC), U7.1 (VOUT)
unnamed: R5.1, U3.35 (PHI2)
unnamed: R5.2, U4.21 (CLK)
unnamed: R6.2, R7.1, U7.8 (SENSE)
unnamed: R9.1, U3.34 (~BE)
unnamed: R10.1, U3.36 (~SO)
unnamed: R11.1, U3.41 (RDY)
unnamed: R12.1, U3.43 (~IRQ)
unnamed: SW1.2, U7.4 (~MR)
SW-CLKA: U4.11 (V1), U4.13 (V3); also elsewhere on the board
SW-CLKB: U4.3 (S0); also elsewhere on the board
SW-RAMSIZE: U2.40 (I); also elsewhere on the board
~MEM_OE: U2.81 (O), U5.22 (~OE), U6.1 (~OE)
~MEM_WE: U2.83 (O), U6.6 (~WE)
~RAM_CE: U6.27 (~CE), U7.6 (~CEout)
~RAM_SEL: U2.79 (O), U7.5 (~CEin)
~ROM2_CE: U2.80 (O), U5.20 (~CE)
~Reset: U3.38 (~RESET), U7.9 (~RESET); also elsewhere on the board
~intNMI: U2.16 (O), U3.1 (~NMI)

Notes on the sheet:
ROM2
SRAM
CPU
Clock-Generation
Reset-Circuit & Battery Management
Decode-Logic Config-Register Transfer-Register
Reset
Mechanical Elements

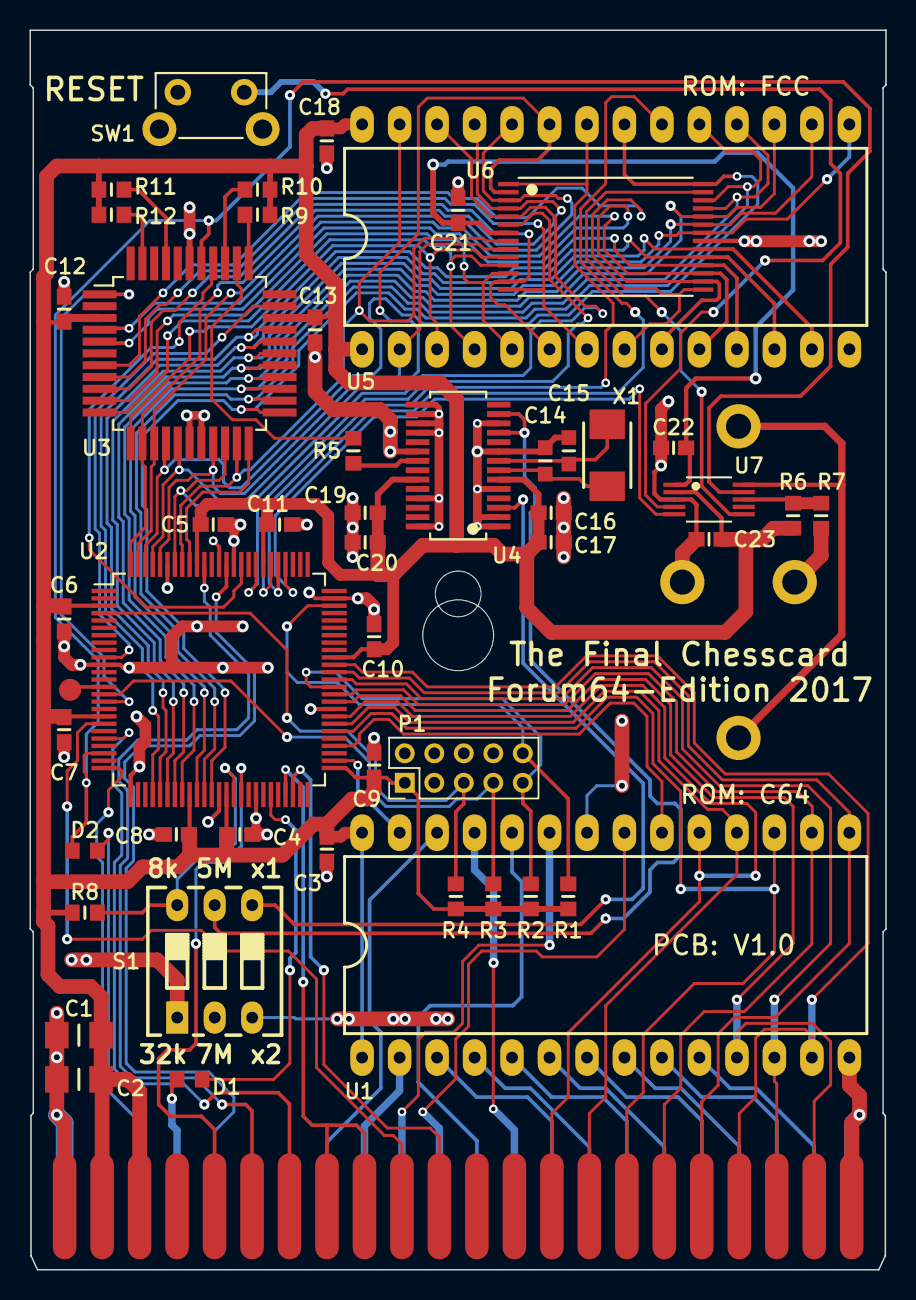
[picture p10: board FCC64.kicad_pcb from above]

Board: 2 copper layers, 58.0 x 84.0 mm, 52 parts (1 on the bottom side), 89 nets.

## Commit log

2017-06-15 Layoutdaten hochgeladen
    [FCC64.kicad_pcb, FCC64.sch, FCC64_Sheet1.sch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]
2017-07-04 Nummerierung der Datenleitungen am C64-Expansionport korrigiert.
2017-07-10 Various issues solved:
    * QFP44-Footprint for W65C02 corrected
    * FCC-On/Off deleted
    * new battery supervisor ic TPS6513-01
    * Battery Holder corrected
    * Signals D5 and D7 to CPLD swapped
    [FCC64.kicad_pcb, FCC64.sch, FCC64_Sheet1.sch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]
2017-07-29 Tidying up for initial batch
    [FCC64.kicad_pcb, FCC64_Sheet1.sch]
2017-09-03 Width of Slot-Connector reduced by 0,1mm
    [FCC64.kicad_pcb]
2017-09-03 Bill of Material created
2017-09-23 PCB Thickness added
